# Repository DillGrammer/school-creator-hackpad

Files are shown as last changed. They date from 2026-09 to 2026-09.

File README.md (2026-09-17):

# Hackpad PCB — revision 1.0

Open **Hackpad.kicad_pro** in KiCad 10. The project includes its own symbol and footprint libraries; no care-package installation is needed. Original Desktop files were left unchanged.

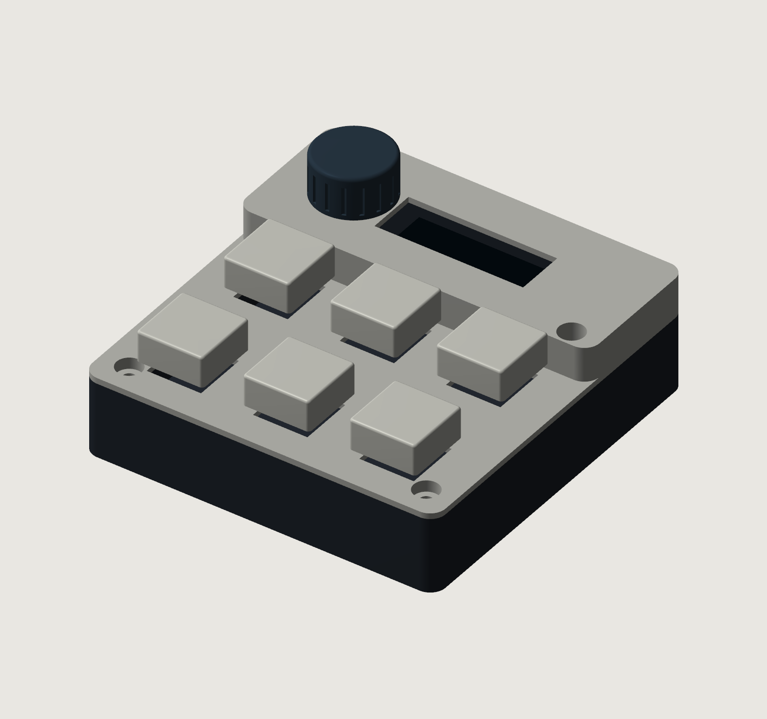
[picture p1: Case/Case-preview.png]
CAD preview of case revision 1.1


CAD visualization, not a photograph of an assembled device.

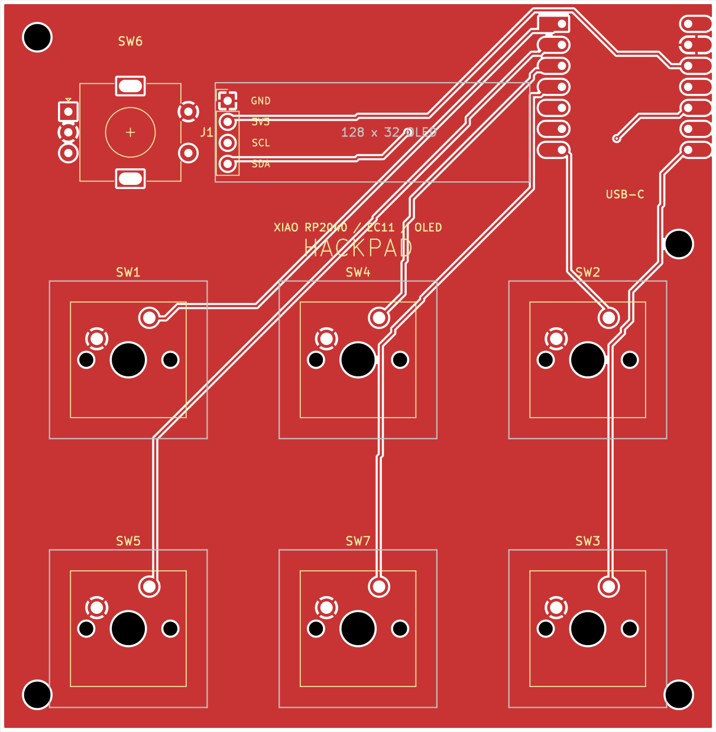
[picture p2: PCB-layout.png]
Routed two-layer PCB layout


This project was substantially generated and revised with ChatGPT/Codex assistance, following the owner's feature/layout choices and design review. See Software/Feature-status.md for unfinished integrations and Submission-status.md for funding status.

## What is finished

- 86.5 × 88.5 mm, two copper layers, 1.6 mm PCB.
- Six soldered MX switches in the established 3 × 2 layout.
- Clickable EC11 at top-left; 0.91-inch OLED immediately to its right.
- Seeed Studio XIAO RP2040 at top-right, USB-C facing the top edge.
- Routed signals, front/back ground pours, four 3.2 mm mounting holes.
- ERC, DRC and schematic parity reports included. All report zero issues.
- Gerber copper, masks, silkscreens, outline, and separate plated/non-plated drill files included.

The matching case is supplied in **Case/** as STEP and STL files, with an assembly guide and geometry checks. The native Fusion `Case/Hackpad_Case.f3d` includes editable base/cover features and a positioned knob. Case revision 1.1 corrects the CAD Y direction and knob placement; use the new case files, not earlier archives. Actual firmware and desktop-helper source are included in **Software/**; this is a development build, not a hardware-tested release. See **Software/Feature-status.md** for the exact remaining integration work.

## Pin map

View from above, USB-C at the top. Key numbers describe physical positions; existing SW references are preserved.

| Control | Reference / pad | XIAO label | RP2040 GPIO | Net |
|---|---|---|---|---|
| Top-left key | SW1 / 1 | D0 | 26 | KEY1 |
| Top-middle key | SW4 / 1 | D2 | 28 | KEY2 |
| Top-right key | SW2 / 1 | D6 | 0 | KEY3 |
| Bottom-left key | SW5 / 1 | D1 | 27 | KEY4 |
| Bottom-middle key | SW7 / 1 | D3 | 29 | KEY5 |
| Bottom-right key | SW3 / 1 | D7 | 1 | KEY6 |
| Encoder rotation A | SW6 / A | D10 | 3 | ENC_A |
| Encoder rotation B | SW6 / B | D9 | 4 | ENC_B |
| Encoder press / Enter | SW6 / S1 | D8 | 2 | ENC_CLICK |
| OLED data | J1 / 4 | D4 / SDA | 6 | OLED_SDA |
| OLED clock | J1 / 3 | D5 / SCL | 7 | OLED_SCL |
| OLED power | J1 / 2 | 3V3 | — | +3V3 |
| OLED ground | J1 / 1 | GND | — | GND |

All key pad 2 connections, encoder C, and encoder S2 connect to ground. Enable input pull-ups and software debounce for keys and encoder press. Use a quadrature decoder for rotation; configure its transitions-per-detent for the supplied encoder so one detent produces one menu step. Reverse direction in firmware if needed. Encoder press is independently wired and can mean Enter/select or another action by mode.

Six keys + three encoder inputs + two OLED signals use all 11 exposed GPIOs. Independent key wiring supports simultaneous presses without a switch matrix or diodes. Extra kit LEDs are not fitted in this design.

## Parts used from the published kit

| Quantity | Part |
|---:|---|
| 1 | Standard Seeed Studio XIAO RP2040, not RP2040 Plus |
| 6 | MX-style through-hole switches |
| 6 | 1u DSA keycaps |
| 1 | EC11 clickable rotary encoder |
| 1 | 0.91-inch 128 × 32 I²C OLED, GND–VCC–SCL–SDA |
| 1 | 4-pin 2.54 mm header supplied with/for OLED |
| 4 | M3 × 16 mm case screws, for planned enclosure |
| 4 | M3 heat-set inserts, for planned enclosure |

## Assembly assumptions

- The supplied encoder matches the Hackpad-style EC11 footprint: A/C/B terminals at 2.5 mm pitch, click terminals opposite, and two slotted metal anchors. Nominal shaft height is 20 mm. A knob is not listed in the published kit; a printable knob can be matched to the supplied shaft during case completion.
- OLED is mounted display-up and extends rightward from J1. **J1 pins run top-to-bottom: GND, 3V3, SCL, SDA.** The module envelope is assumed to be 38 × 12 mm; it is shown in the project footprint and drawing layer. Confirm the actual supplied module uses that header orientation before soldering.
- OLED is powered from 3.3 V. The common module includes I²C pull-ups; confirm that the supplied module has pull-ups to 3.3 V. Do not connect I²C pull-ups to 5 V. The MCU's weak internal pull-ups alone are not the design basis for a reliable I²C bus.
- XIAO uses the existing care-package hybrid footprint, with corrected RP2040 schematic pin names. Direct solder mounting is assumed for the planned case; tall sockets change the case fit.
- USB supplies the XIAO directly. Its 5 V breakout is deliberately unused. The circuit has no battery input.
- Switches are soldered, not hot-swap. The upper row was aligned to a common centre line; the original column spacing and lower row were preserved.
- EC11 switch anchor pads are mechanical only. They do not substitute for the C/S2 ground connections.

## Mechanical coordinates

Millimetres from PCB top-left; X right, Y down.

| Item | X | Y |
|---|---:|---:|
| Key column centres | 15.50 / 43.25 / 71.00 | — |
| Key row centres | — | 43.50 / 76.00 |
| Encoder shaft centre | 15.75 | 16.00 |
| OLED GND header pin | 27.50 | 12.19 |
| XIAO footprint centre | 75.50 | 10.50 |
| Mount H1 | 4.50 | 4.50 |
| Mount H2 | 82.00 | 29.50 |
| Mount H3 | 4.50 | 84.00 |
| Mount H4 | 82.00 | 84.00 |

The matching case uses a rounded base and removable stepped cover, four M3 screws and heat-set inserts. See **Case/Assembly-guide.md** for the assembly order, printing orientation and component fit assumptions.

## Manufacturing files

Use the Gerbers ZIP, including both drill files, for the PCB only. Board specification: two layers, FR-4, 1.6 mm thickness; design uses 0.25 mm traces, 0.20 mm minimum clearance, 0.60/0.30 mm vias, and 0.50 mm minimum copper-to-edge clearance. The Stardance design project has been created; no funding application or manufacturing order has been submitted. See Submission-status.md.

The checks validate the CAD files; this design has not been physically assembled or tested. The case has CAD checks but no physical print test; software has automated logic/display tests but still requires hardware and app integration testing.

## Sources

- [Hackpad / Stardance](https://hackpad.hackclub.com/)
- [Hack Club published kit contents](https://blueprint.hackclub.com/hackpad/parts)
- [Hackpad component guidance](https://hackpad.hackclub.com/add-components)
- [Seeed XIAO RP2040 pin map](https://wiki.seeedstudio.com/XIAO-RP2040/)

Footprints are derived from KiCad's installed libraries and the user's existing Hackpad care package. The XIAO's fabrication graphics were retained, and its courtyard added. The OLED header footprint was expanded to describe the full module envelope.

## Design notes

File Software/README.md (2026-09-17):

# Hackpad software — development build

This folder contains actual CircuitPython firmware, a Mac/Windows Python helper, and automated tests. It is **not a hardware-tested release**. Read `Feature-status.md` before relying on advanced actions.

## Install the helper

1. Install Python 3.11 or newer from python.org, including Tk support (the standard python.org installer includes it).
2. On Mac, open `Start-Mac.command`; on Windows open `Start-Windows.cmd`. First launch creates a local environment and installs dependencies from PyPI. Internet access is needed for that installation.
3. In the setup window, use **Import settings** to load your private settings file, or fill the tabs manually. Choose folder locations with **Choose…**. Missing entries disable only their associated actions.
4. Save settings. They stay in your user account's Hackpad application-data folder. Passwords and API keys are not in the firmware or public project.
5. For Quick Answer, set a vision-capable OpenAI API model and enter its key through **Set AI key privately**. The key is stored in the OS credential store. This is a separate API workflow from ChatGPT browser conversations.
6. macOS may request Accessibility/Input Monitoring for keyboard actions and Screen Recording for captures. Only enable the permissions for the Python/helper you choose to run. No permission is bypassed automatically.

If you enable the optional separate helper browser, install its Chromium runtime once with `.venv/bin/python -m playwright install chromium` on Mac, or `.venv\Scripts\python.exe -m playwright install chromium` on Windows. Log in in that separate browser when prompted. Existing browser sessions are not copied. Chat drafts are never sent automatically and video uploads are never published or scheduled.

## Install firmware

1. Download the stable CircuitPython UF2 **for Seeed Studio XIAO RP2040**, not another XIAO board: https://circuitpython.org/board/seeeduino_xiao_rp2040/
2. Enter the board's BOOTSEL mode and copy the UF2 to its boot drive. Wait for `CIRCUITPY` to appear.
3. Copy the contents of `firmware/` to the root of `CIRCUITPY`, including `lib/`, `font5x8.bin`, `engine.py`, `device.json`, `boot.py`, and `code.py`.
4. Reconnect USB. The firmware uses the exact pin map in the PCB project. Default OLED I²C address is 0x3C. In `device.json`, adjust encoder divisor (typically 2 or 4) and direction if one detent is not one menu step. Check the supplied encoder instead of assuming its pulse count.
5. Start the helper and choose Mac or Windows on the OLED. The helper scans common XIAO/CircuitPython USB vendors and confirms a protocol handshake before accepting commands. If needed select the serial port explicitly in Setup.

No UF2 has been flashed here and no physical OLED/input test has been performed. USB endpoint compatibility, memory usage and the downloaded CircuitPython release must be checked on the board. The firmware uses USB serial only; the helper is the single action dispatcher, so HID and helper commands cannot double-fire. It does not act as a standalone keyboard without the helper.

## Controls

- Boot: turn and click to choose Mac/Windows.
- Root pages: turn to Courses, Creator, Gaming (Windows), Apps, or More. Titles are brief; six labels remain visible on normal grids.
- Course and action grids: press the corresponding physical key. Small dialogs use turn-and-click.
- Back: hold bottom-right key, click encoder. The sixth key's ordinary action happens on release only if the combination did not consume it.
- CapCut: knob scrubs; click plays/pauses. Hold Volume or Trim and turn to adjust. Tap Volume enters adjustment; Trim lets you choose start/end. Hold Undo for 0.6 seconds for Redo.
- Gaming: at its root page, turn still changes categories. Click once (or press a gaming key) to enter volume control. After that, rotation controls only the foreground app's audio. Back returns to category rotation. This explicit entry avoids guessing whether a turn means category change or volume.
- Gaming keys: Fortnite / Valorant / Discord / Spotify / Next / Previous. OLED shows foreground-app icon/name, volume, and the selected headset microphone's Windows mute state. Unknown mic state displays `?`. A hardware mute switch needs device-specific verification.

## Configuration and fallbacks

School URLs and conversation URLs remain editable. The supplied Math conversation is reused; screenshots and text are prepared without pressing Send. The default reliable path presents a local draft plus an Open Conversation button and screenshot. Optional browser attachment depends on the actual page having its expected editor/file input; it refuses to overwrite a nonempty draft.

CapCut bindings are intentionally explicit in Setup. Enter comma-separated key names, such as `command,z` for an actual verified Mac Undo binding. Each action checks that CapCut is foreground before injecting keys. There are no assumed bindings for volume, trimming or presets; if the installed application does not expose a suitable shortcut, that operation needs a native accessibility adapter and currently reports missing configuration. Do not invent key combinations to make a control appear complete.

Import Recent identifies a stable recent supported file. On Mac, the native import adapter enters the path and checks the selected filename before pressing Import; this adapter still needs an end-to-end helper test. Windows currently copies the path for manual selection.

For Photos on Mac, choose Import → Photos → Open Photos, select one photo or video in Photos, then choose Import chosen on the pad. The helper exports that selected original into its retained imported-media folder, opens CapCut and requests import. macOS Automation permission for Photos is required. The Photos adapter is implemented against the installed Photos scripting dictionary but has not been integration-tested. Live Photos that export both a still and a video require choosing the desired exported file with Selected. Do not delete retained imported media while a CapCut project references it. Windows uses Selected instead.

Export opens the configured dialog, showing the configured Fitness destination; it does not yet verify/apply export settings or detect completion automatically. Set the completed output in Setup before Prepare Upload.

On Windows, an empty app path triggers discovery of exact-name Fortnite, VALORANT, Discord, Spotify or CapCut shortcuts in the user/shared Start Menus and Desktop. A configured path takes precedence. Missing shortcuts still require choosing the app in Setup; discovery has automated filesystem tests but has not been tried on the user's gaming PC.

## Tests

Run `python3 -m unittest discover -s tests -v` from this folder. Tests cover state transitions, held-key consumption, grid dimensions, framebuffer rendering, and non-overwriting copies. They do not prove hardware timing, platform permissions, application UI behavior or physical fit.

## Dependencies

OLED libraries/font come from the official Adafruit repositories; licenses are under `firmware/licenses/`. Dependency hashes are recorded in the packaged manifest. The desktop requirements are in `helper/requirements.txt`. Runtime credentials, browser profiles, screenshots and private settings must never be committed to the public repository.

### Active Word document → class folder

The course Copy key now targets the Word document being edited in the active Safari tab on Mac. It uses Word’s File → Create a Copy → Download a copy command, waits for a new complete DOCX matching that document’s title, and copies it without overwriting existing class files. The original online document stays open. Set each class folder in Setup. Safari must download automatically into Downloads, or set `word_downloads_folder` to its actual destination; Ask for each download requires manual intervention. The helper needs Mac Accessibility permission. English Word control labels were inspected in Safari; the helper’s native adapter itself still requires an end-to-end runtime test. Windows support for this action is not implemented.

### Validation update

The Mac dependency installation and import checks pass, including Tk after installing the missing Homebrew Tk component. The setup window itself has not been launched through computer control because that tool blocks Terminal. Startup now tracks the requirements file and retries dependency installation after failures or changes. Mac CapCut defaults were read from its Shortcuts window: Space, Command-Z, Command-Shift-Z, Command-I, Command-E. Advanced commands remain unconfigured. Upload preparation locally decodes the complete selected video, requires 1080×1920 at approximately 30 fps, checks that the file did not change, and stops on cancellation before attachment. It never publishes.

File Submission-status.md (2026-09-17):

# Submission status — September 17, 2026

**Not submitted. This is a development package, not a completed/validated build.** The user authorized submission after completion; that condition has not yet been met.

The [School & Creator Hackpad project](https://stardance.hackclub.com/projects/63122) now exists in the signed-in Stardance account. Its stage is Design. The factual description and substantial AI-assistance declaration were saved and confirmed by the site. No devlog, funding application, grant claim or shipment has been submitted.

The project currently shows zero devlogs and zero hours. Submit for funding is disabled. The devlog form explicitly says: "Timelapse for at least 15m before devlogging (currently 0m logged)." No unrelated project time was linked and no recording or human work hours were fabricated.

The [public source repository](https://github.com/DillGrammer/school-creator-hackpad) is now published and linked on Stardance. It includes the PCB, Gerbers, native Fusion/STEP/STL files, software source, tests and images. A CAD-render banner was attached and explicitly identified as a render in the description. The separate public staging tree excludes private settings, school links, raw conversation attachments and local error logs.

For this project the appropriate first submission is the **Hackpad design/kit stage**, not a claim that physical assembly is complete. The official mission lists kit, PCB and printing support after design; build rewards are separate. The public hardware guide asks for CAD STEP, PCB source, firmware, BOM and README, with a public repository. See [Hackpad mission](https://stardance.hackclub.com/missions/hackpad) and [hardware submission guide](https://stardance.hackclub.com/resources/shipping-hardware).

Prepared: PCB source and libraries, Gerbers, zero-issue ERC/DRC reports, STEP/STL case files, firmware/helper development source, automated tests, BOM and documentation.

Remaining:

- Native Fusion export is now produced. Case revision 1.1 fixes the knob placement and handedness. Physical fit is still untested.
- Finish and validate the advanced CapCut, Photos and upload adapters detailed in Software/Feature-status.md. Current fallback paths are documented; they are not full automation.
- Hardware input/display checks and Windows audio/headset checks require the actual board and Windows PC. Design-stage review may precede physical assembly, but evidence must describe that honestly.
- Keep the published development repository synchronized with reviewed fixes. Do not include Private settings, completed setup sheet, personal conversation URLs, screenshots of schoolwork, API keys, or browser profiles.
- The owner must supply authentic recorded work and their own devlog through Stardance's normal workflow; funding submission is currently disabled. This is distinct from physical assembly, which is not required for the design stage.
- Complete the real mission form with factual details; do not fabricate tracked hours, devlogs, eligibility or build photos. Any required personal answers must come from the user.

The published kit specification lists the matching XIAO, MX switches, EC11, 0.91-inch GND/VCC/SCL/SDA OLED, M3×16 screws and M3×5×4 inserts: [kit contents](https://blueprint.hackclub.com/hackpad/parts). Module/shaft variations and print tolerances still need fit confirmation.

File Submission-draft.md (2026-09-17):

# Proposed Stardance design-stage submission

Six-key Hackpad for school, video editing and Windows gaming, with a clickable encoder and a 128×32 OLED. The two-layer 86.5×88.5 mm PCB uses a XIAO RP2040 and direct switch wiring. The OLED sits immediately to the right of the encoder, and USB-C exits at the top.

The case uses two printed shell parts, four M3 screws and heat-set inserts, plus an optional printed knob. Revision 1.1 corrects the CAD orientation and knob placement. Editable Fusion, STEP, STL, KiCad source, Gerbers, pin map, BOM and software source are included in the development archive.

Status: design and software prototype, not a physically assembled product. The case is checked against modeled component envelopes; exact supplied parts and print fit still need confirmation. Firmware input/display logic and selected helper functions have automated tests. Several app integrations remain unfinished or unverified, as listed in Software/Feature-status.md.

AI assistance: code, PCB/CAD generation and automated checks were assisted by Codex. No human work hours, physical build evidence or eligibility claims are supplied by this draft.

This draft has not been submitted. Appropriate route after readiness review: design funding/kit request, not an assembled-build reward claim. Required personal or eligibility responses must be supplied by the project owner.

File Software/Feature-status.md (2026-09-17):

# Feature status — September 17, 2026

A function having source code is not equivalent to being validated on the user's computer or hardware.

| Area | Implemented | Remaining verification/work |
|---|---|---|
| Input/menu firmware | Actual state machine, physical pins, debounce, OLED grids, OS selection, global Back, held controls | Flash and test actual XIAO/OLED/encoder; confirm detent divisor |
| Helper setup | GUI, folder pickers, private JSON import, OS key store | Mac dependencies installed and imported successfully; GUI launch requires user action because Terminal is blocked by computer control; Windows installation untested |
| USB protocol | Handshake, bounded queues, duplicate IDs, cancellation, reconnect, OS mismatch rejection | Physical USB testing |
| Courses | Configured URL launch, drafts, screenshot capture, folder picker, rename, username entry; active Safari Word download-and-copy adapter | Word adapter source not yet run end-to-end; Mac Accessibility permission; class folders; Windows Word adapter not implemented |
| Quick Answer | On-demand capture, API request, short OLED answer, explanation log, cancellation | API model/key and real capture tests |
| ChatGPT drafts | Local draft fallback; optional browser fill/attachment without Send | Validate current ChatGPT editor/attachment behavior and login |
| CapCut basic controls | Foreground-checked configurable shortcuts; Mac play/pause, undo, redo, import and export defaults read from CapCut | Test commands on media; Windows shortcuts and advanced controls unverified |
| CapCut volume/trim/text/transition | Dispatcher and configurable bindings | Native app adapter where no shortcut exists; preset selection not implemented |
| Media import | Recent/selected file handling; Mac native picker adapter; selected-original Photos export and separate Open/Import menu | End-to-end helper test for Mac picker and Photos permissions/export; Windows uses manual path fallback |
| Export | Export shortcut and Fitness destination prompt | Set/verify 1080×1920 30 fps settings, execute export, verify completion automatically |
| Upload preparation | Optional file-input attachment; manual fallback; no publish/schedule code | Real video decoding now rejects incomplete files and non-1080×1920/30 fps exports; both real upload editors still require validation |
| Gaming | Launch targets, exact-name installed Windows shortcut discovery, Spotify-specific transport, per-app volume, foreground icon, selected headset capture-endpoint mute | Windows and actual headset tests |
| Case | Revision 1.1 STEP/STL and native Fusion F3D; corrected handedness and knob position; solid and mesh checks | Physical fit check; actual kit dimensions |
| Submission | Public DillGrammer/school-creator-hackpad repository; Stardance design project 63122 with source link, CAD render, factual description and AI declaration | Authentic recorded work/devlog and advanced integration work; funding submission remains disabled |

Do not submit this as a fully tested or physically assembled product. Do not invent hours, devlogs, photographs, build evidence or eligibility claims. Generated mockups are not photos of a real build.

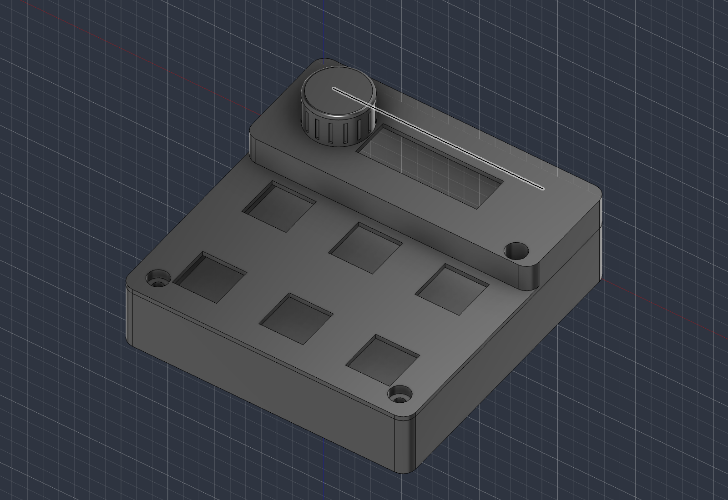
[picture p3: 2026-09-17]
Case/Fusion-preview.png

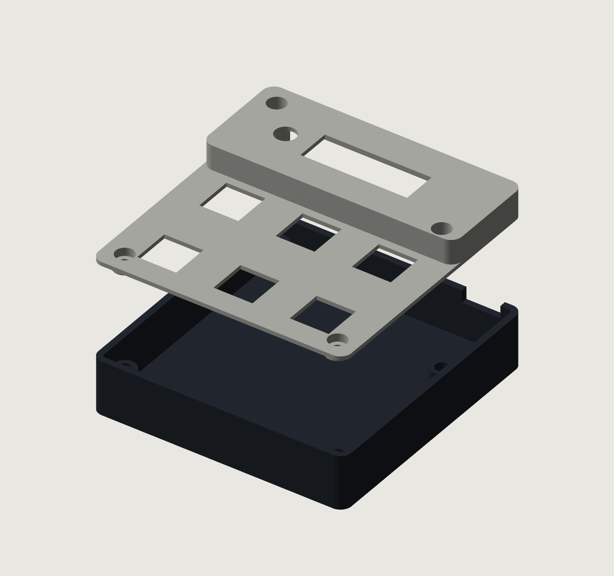
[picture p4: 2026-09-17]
Case/Case-exploded.png

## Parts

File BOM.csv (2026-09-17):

Item | Quantity | Specification | Source | Notes
Microcontroller | 1 | Seeed Studio XIAO RP2040 | Hackpad kit | Direct solder mounting; not RP2040 Plus
Switch | 6 | MX through-hole | Hackpad kit | Soldered; no hot-swap sockets
Keycap | 6 | 1u DSA | Hackpad kit | Blank white
Rotary encoder | 1 | EC11 with push switch | Hackpad kit | Confirm shaft geometry against case
OLED | 1 | 0.91 inch 128x32 I2C | Hackpad kit | Pin order GND VCC SCL SDA
OLED header | 1 | 1x4 2.54mm | OLED hardware | Nominal module underside 8.5mm above PCB
Screw | 4 | M3x16mm | Hackpad kit | Head diameter <=5.7mm and height <=3mm
Heat-set insert | 4 | M3 OD5mm length4mm | Hackpad kit | Case pilot diameter 4.6mm
PCB | 1 | 86.5x88.5mm 2-layer FR4 1.6mm | PCB fabrication | Gerbers included
Base print | 1 | Base.stl | 3D printing | No damping
Cover print | 1 | Cover.stl | 3D printing | Print orientation supplied
Knob print | 1 | Knob.stl | 3D printing | Optional; nominal 6mm D shaft
USB cable | 1 | USB-C data cable | User supplied | Data-capable cable required

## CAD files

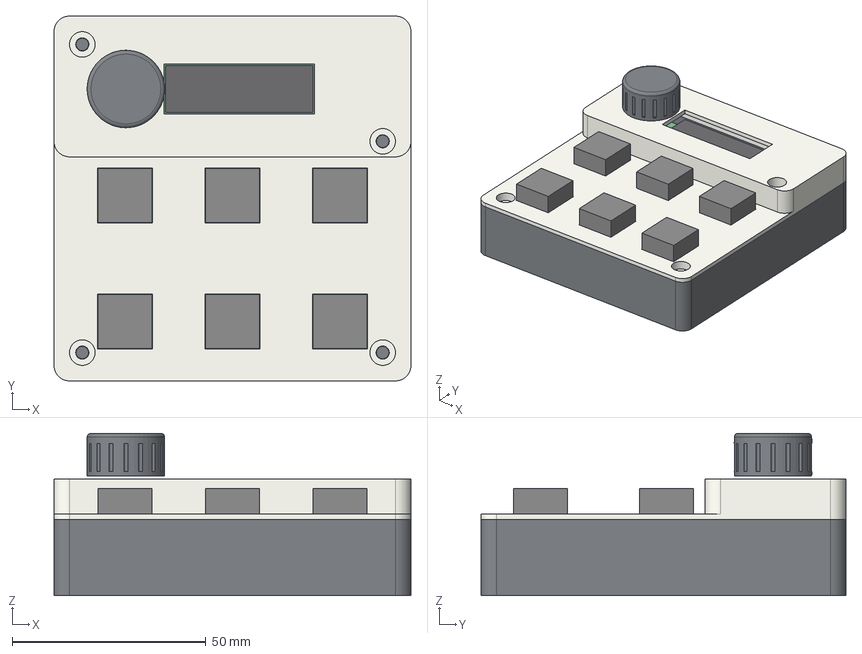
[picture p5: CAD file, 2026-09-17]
Case/Hackpad_Assembly.step
92.1 x 94.1 x 41.9 mm
Base
Cover
Knob_with_0p8mm_click_clearance
REFERENCE_PCB_envelope
REFERENCE_OLED_module
REFERENCE_XIAO_envelope
REFERENCE_switch_1
REFERENCE_switch_2
REFERENCE_switch_3
REFERENCE_switch_4
REFERENCE_switch_5
REFERENCE_switch_6

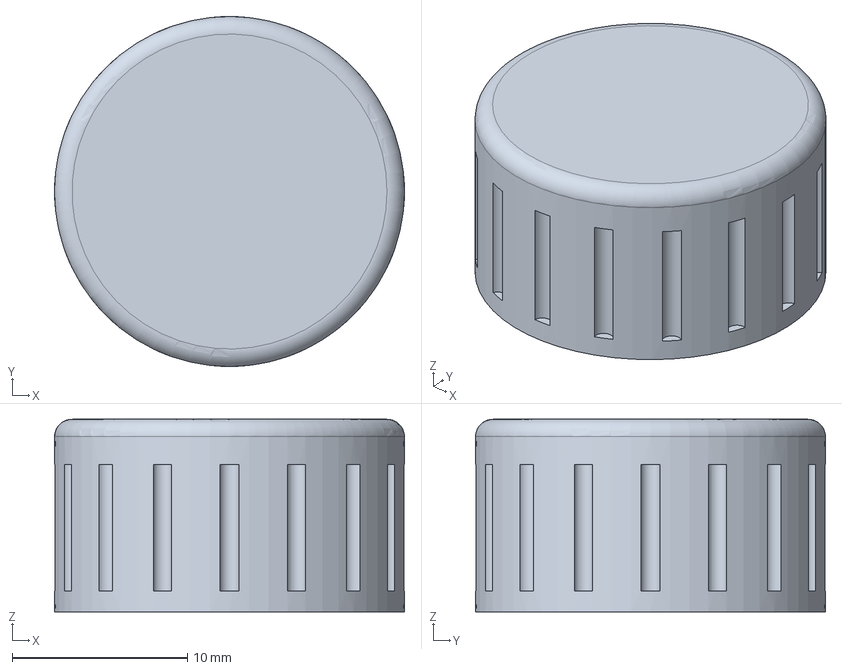
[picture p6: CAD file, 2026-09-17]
Case/Knob.step
20.0 x 20.0 x 11.0 mm

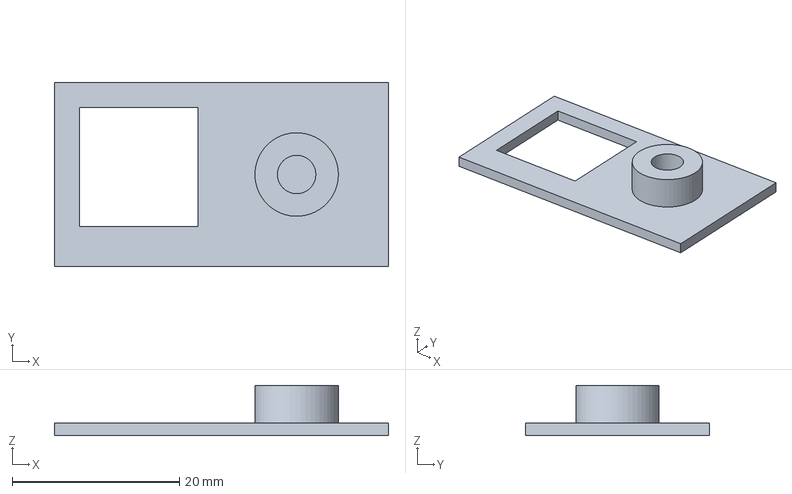
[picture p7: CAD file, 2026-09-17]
Case/Fit_coupon.step
40.0 x 22.0 x 6.00 mm

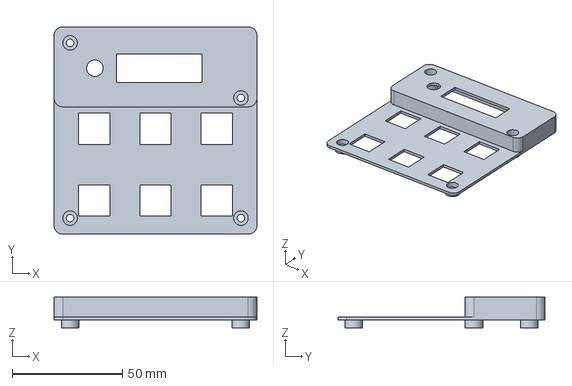
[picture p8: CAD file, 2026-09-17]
Case/Cover.step
92.1 x 94.1 x 14.0 mm

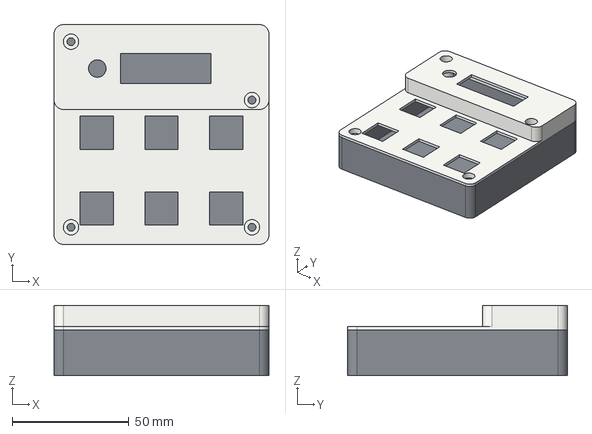
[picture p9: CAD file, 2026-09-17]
Case/Hackpad_Case.step
92.1 x 94.1 x 30.1 mm
Base
Cover

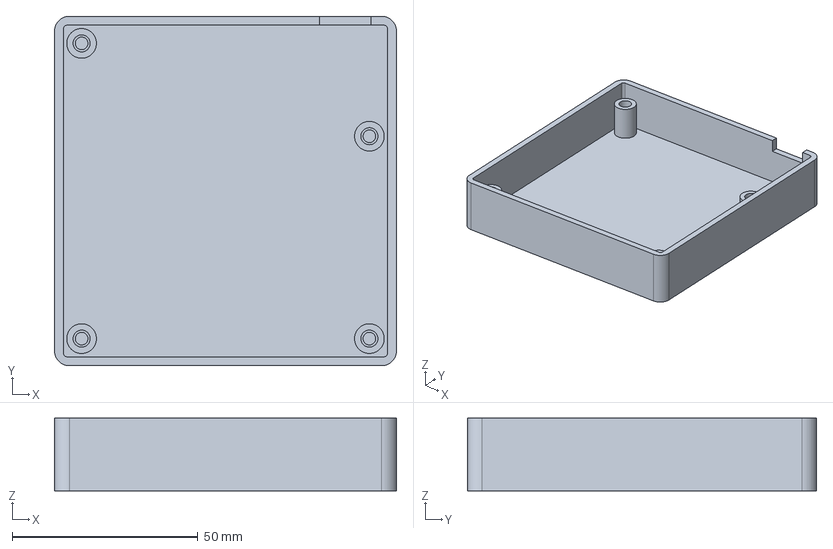
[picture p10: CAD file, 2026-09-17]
Case/Base.step
92.1 x 94.1 x 19.6 mm

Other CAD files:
Case/Base.stl
Case/Cover.stl
Case/Fit_coupon.stl
Case/Hackpad_Case.f3d
Case/Knob.stl

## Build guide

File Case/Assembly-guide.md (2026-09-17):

# Hackpad case

A simple rounded base and one removable cover, with six MX openings, a clickable encoder, an OLED recess and a USB-C opening. No foam, gaskets or damping layers are used.

## Files

- **Base.stl** and **Cover.stl**: the two main printed parts, already oriented for printing.
- **Knob.stl**: optional printed knob for a nominal 6 mm D-shaped EC11 shaft.
- **Hackpad_Case.step**: assembled solid model that can be opened in Fusion. Separate STEP files are also included.
- **Fit_coupon.stl**: optional small test of the MX opening and heat-set insert fit. It is a test piece, not part of the final case.

**Revision 1.1:** `Hackpad_Case.f3d` is the native Fusion model with editable base/cover features. The knob is centered over the encoder with its bottom at 30.9 mm, 0.8 mm above the hood. The CAD Y axis is the negative of KiCad top-view Y, so the encoder is top-left and OLED to its right. Replace earlier case files and archives; those had an incorrect handedness and native knob placement.

## Hardware

Use four M3 × 16 mm screws and four M3 heat-set inserts (assumed 5 mm outside diameter × 4 mm length). The screw recesses allow heads up to 5.7 mm diameter and 3.0 mm high. The insert pilot holes are 4.6 mm diameter and 4.2 mm deep. Install the inserts flush or slightly below the top of each base post.

The case matches the supplied Hackpad PCB revision 1.0: 86.5 × 88.5 mm, 1.6 mm thick, with mounting holes at (4.5,4.5), (82,29.5), (4.5,84), (82,84) mm. Case size is **92.1 × 94.1 mm**, 21.1 mm tall at the key plate and 30.1 mm at the control hood, excluding keys and knob.

## Assembly order

1. Remove print supports and test the switch and insert fit. Install the four heat-set inserts in the base **before fitting the PCB**.
2. Solder the XIAO directly to the PCB; fit the EC11 and OLED. The case assumes an OLED underside 8.5 mm above the main PCB, and a module up to 38 × 12 mm.
3. Snap the six MX switches into the cover from above. **Do this before soldering the switches to the PCB**; an assembled switch's upper flange cannot pass through the plate opening.
4. Bring the PCB up underneath the cover, align the six sets of switch pins, encoder shaft and OLED opening, then solder the switch pins from below.
5. Place that assembly into the base. Install the four M3 × 16 mm screws through the cover and PCB into the base inserts; tighten gently. The lower screw heads sit flush with the key plate. The upper two are reached through the recessed screw wells.
6. Fit the keycaps. If using the printed knob, align its D-shaped socket and leave **at least 0.8 mm between knob and hood** so the encoder can still be pressed. Do not force the knob fully down against the hood.

The cover comes off with four screws for later access. There are no loose internal spacers.

## Printing

A practical starting point is PLA, a 0.4 mm nozzle, 0.2 mm layers, four walls and 25–35% infill. The switch plate is 1.5 mm thick; switch openings are 14.2 mm square.

- Base.stl is bottom-down. Supports are generally unnecessary except if the printer needs help at the USB cutout.
- Cover.stl is already upside-down with the control roof toward the bed. **Enable supports from the build plate under the elevated key-plate area.** Keep support material out of the small holes when the slicer allows it. Remove supports before assembly.
- Knob.stl is socket-down; its internal roof is a short bridge.

The two colours in the preview are only a suggestion: print the base dark and cover light, or use one colour.

## Checks and fit assumptions

Each printable item is one valid CAD solid. Exported meshes have zero boundary/non-manifold edges. The modeled PCB, switches, OLED, encoder, screws and inserts have no volumetric collisions with the case. Reports are included.

Physical printing and assembly have not been tested. Before printing the full case, confirm the kit's insert dimensions, encoder shaft shape/height, OLED header height and screw head dimensions. The XIAO must be directly soldered; tall header sockets would need a case adjustment. The printed knob is optional because EC11 shaft variants differ. The preview uses illustrative keycaps and display glass.

## Additional reproducible files

`Hackpad_Assembly.step` contains the actual base, cover and optional knob with 0.8 mm click clearance, plus explicitly named REFERENCE component envelopes. The reference blocks are not manufacturer component models. Use the PCB files and component specifications for exact pin geometry.

`FusionBuild/FusionBuild.py` is the corrected native Fusion builder. Its base and cover dimensions match the checked STEP parts. In a new empty **Hybrid design**, open Scripts and Add-Ins and select this script folder, then run it. It creates editable base/cover features and imports the optional knob solid, exporting `Hackpad_Case.f3d` and a geometry report into this Case folder. The corrected script has executed successfully. Native solid volumes match the separate STEP geometry; its export includes a checked knob position. Do not use the older script in the working directory.

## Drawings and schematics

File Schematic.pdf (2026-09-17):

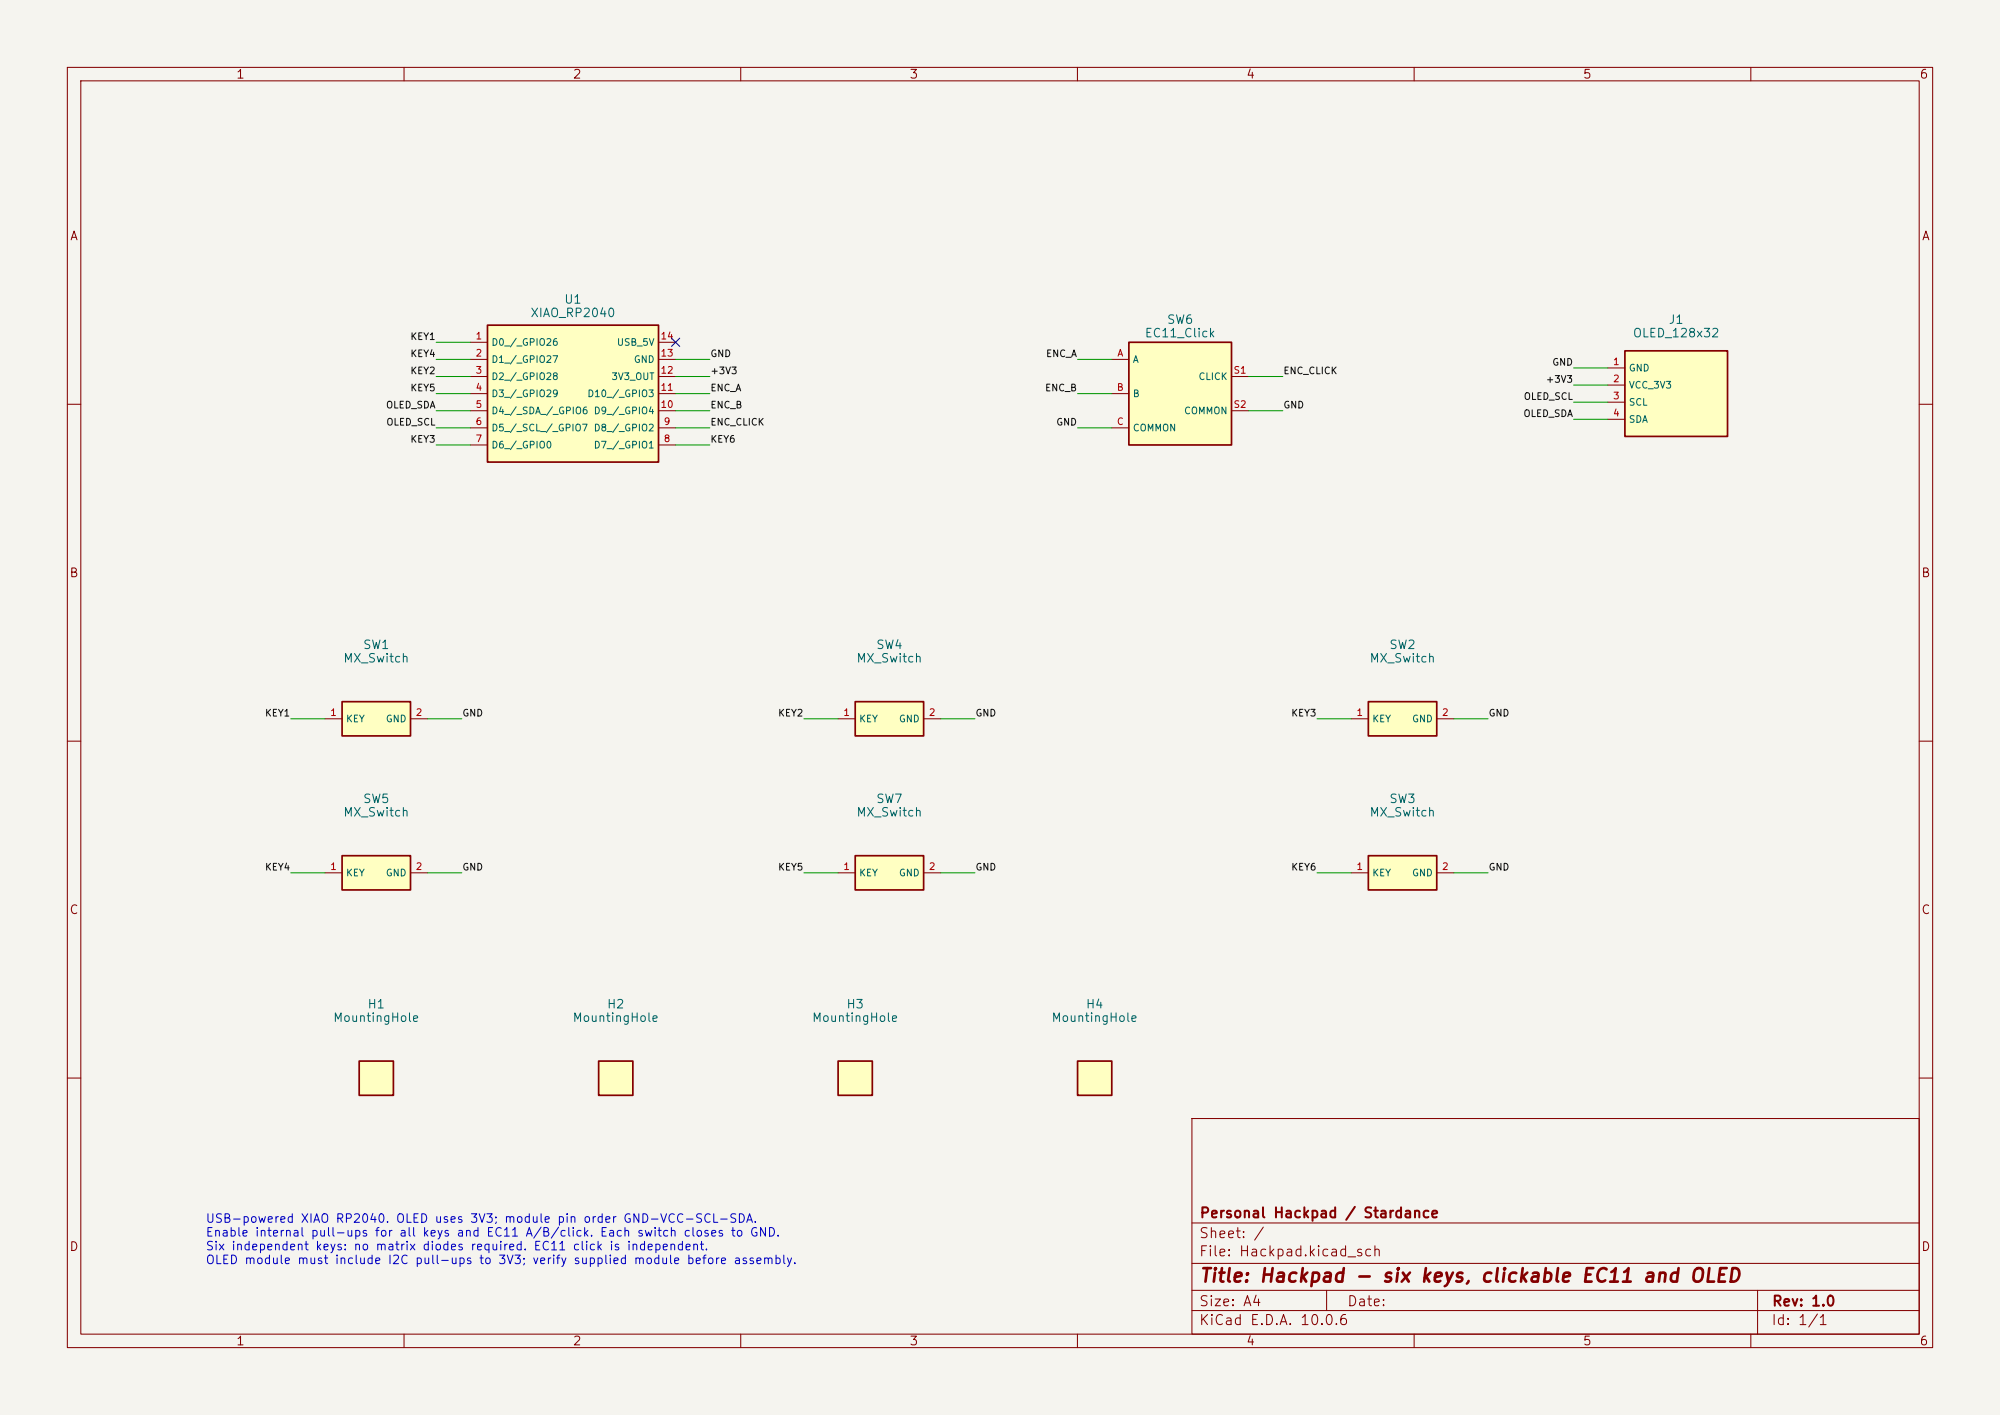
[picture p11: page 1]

Personal Hackpad / Stardance
Sheet: /
File: Hackpad.kicad_sch
Title: Hackpad - six keys, clickable EC11 and OLED

Size: A4 | Rev: 1.0
KiCad E.D.A. 10.0.6 | Id: 1/1

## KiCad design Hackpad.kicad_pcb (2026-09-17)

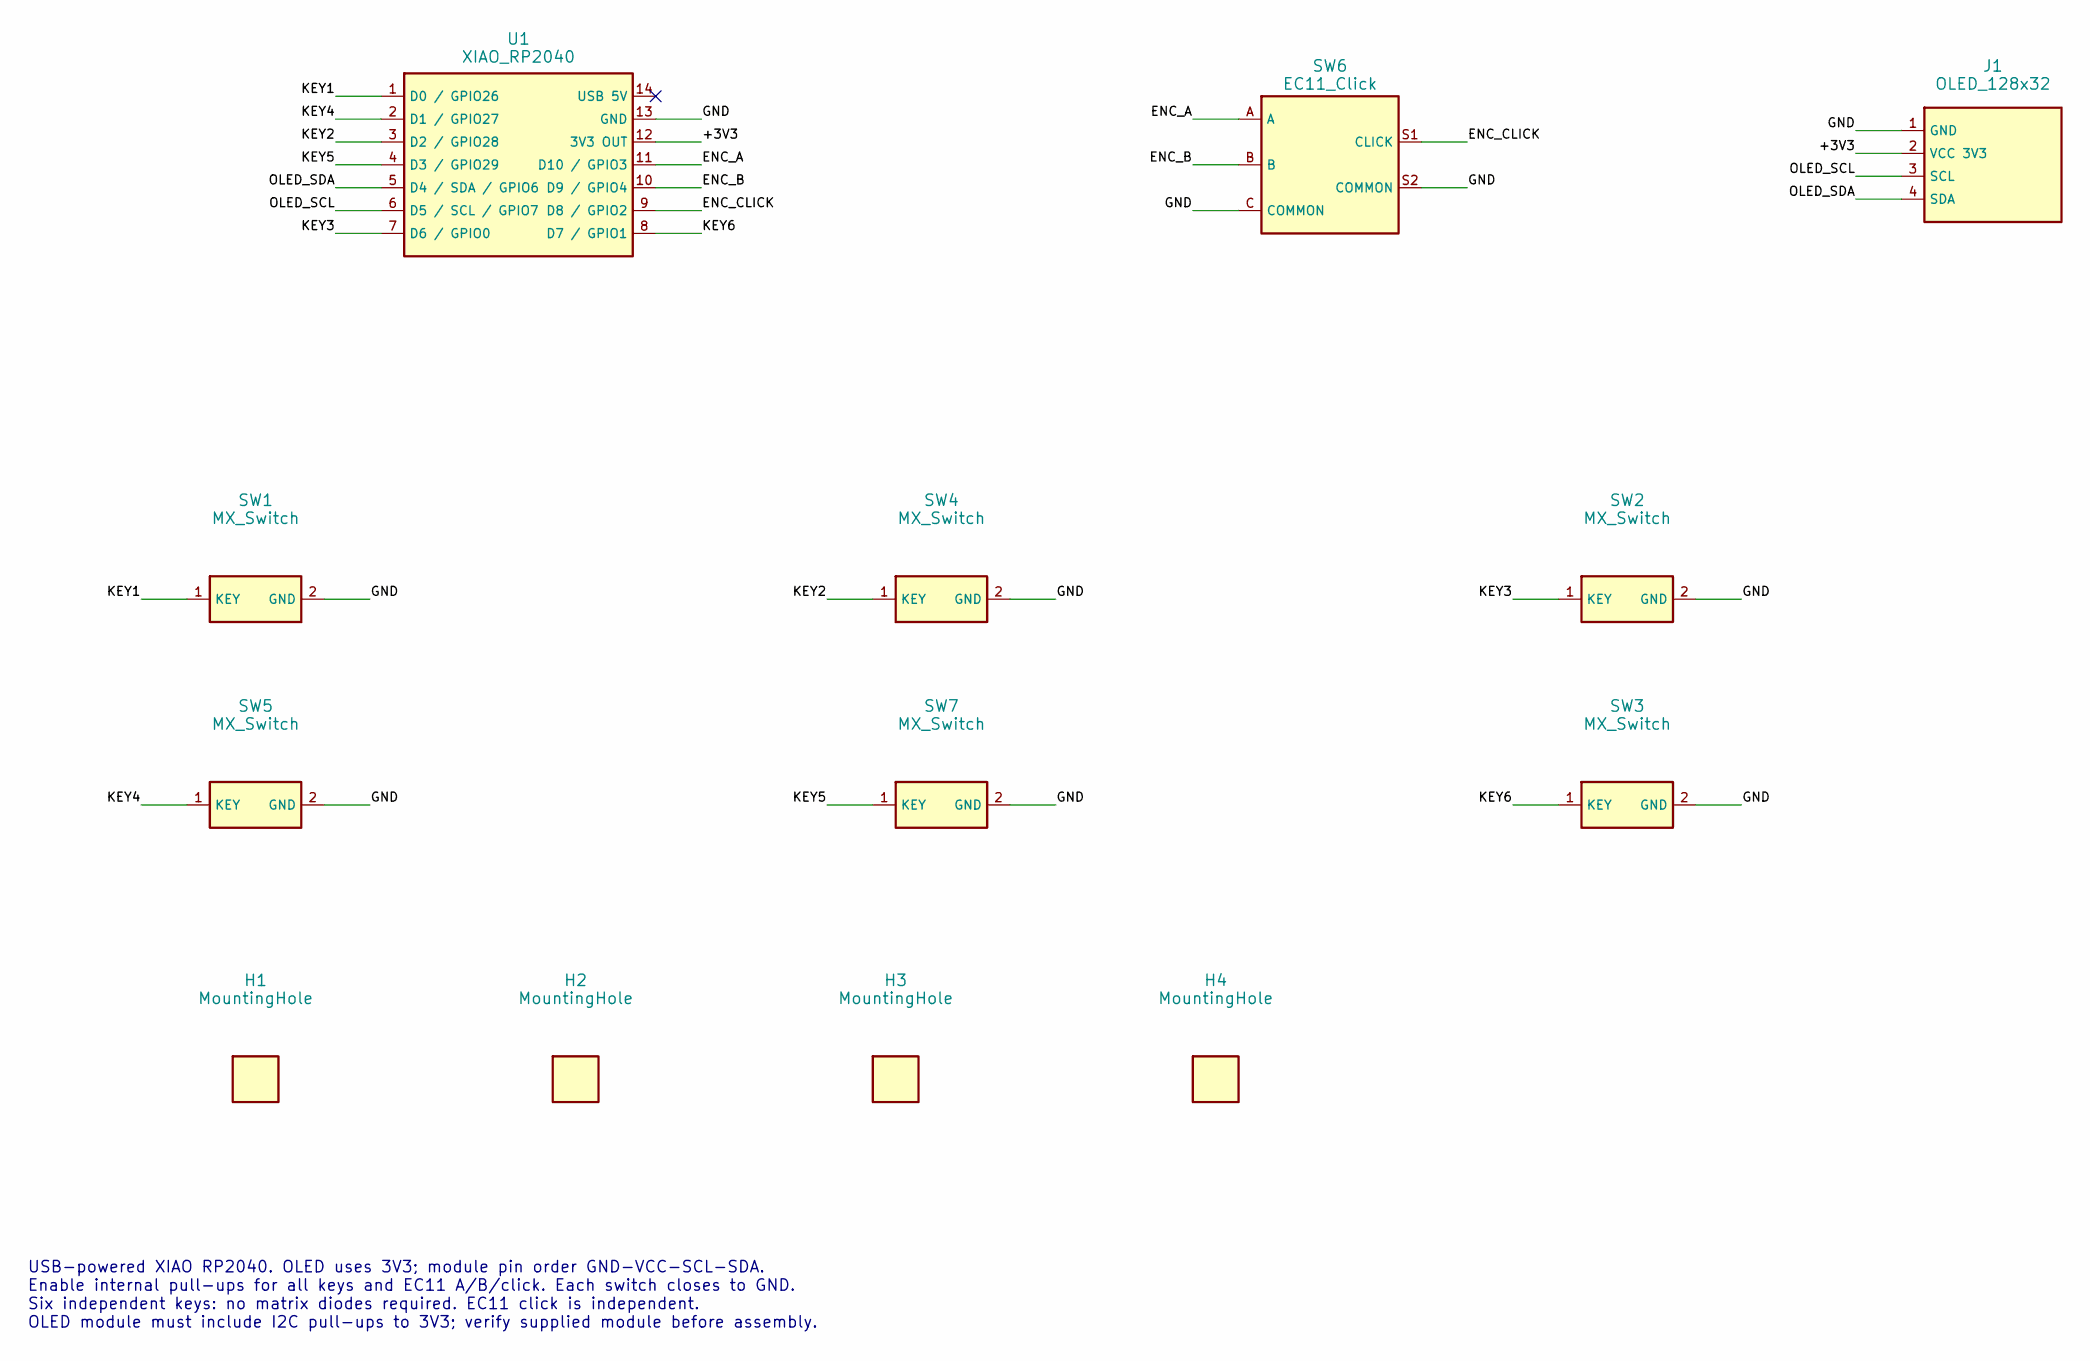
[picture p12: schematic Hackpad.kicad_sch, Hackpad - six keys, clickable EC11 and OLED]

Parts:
H1, H2, H3, H4: MountingHole; MountingHole_3.2mm_M3
J1: OLED_128x32; OLED_091_GND_VCC_SCL_SDA
SW1, SW2, SW3, SW4, SW5, SW7: MX_Switch; SW_Cherry_MX_1.00u_PCB
SW6: EC11_Click; RotaryEncoder_Alps_EC11E-Switch_Vertical_H20mm
U1: XIAO_RP2040; XIAO-Generic-Hybrid-14P-2.54-21X17.8MM

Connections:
/+3V3: J1.2 (VCC 3V3), U1.12 (3V3 OUT)
/ENC_A: SW6.A, U1.11 (D10 / GPIO3)
/ENC_B: SW6.B, U1.10 (D9 / GPIO4)
/ENC_CLICK: SW6.S1 (CLICK), U1.9 (D8 / GPIO2)
/GND: J1.1 (GND), SW1.2 (GND), SW2.2 (GND), SW3.2 (GND), SW4.2 (GND), SW5.2 (GND), SW6.C (COMMON), SW6.S2 (COMMON), SW7.2 (GND), U1.13 (GND)
/KEY1: SW1.1 (KEY), U1.1 (D0 / GPIO26)
/KEY2: SW4.1 (KEY), U1.3 (D2 / GPIO28)
/KEY3: SW2.1 (KEY), U1.7 (D6 / GPIO0)
/KEY4: SW5.1 (KEY), U1.2 (D1 / GPIO27)
/KEY5: SW7.1 (KEY), U1.4 (D3 / GPIO29)
/KEY6: SW3.1 (KEY), U1.8 (D7 / GPIO1)
/OLED_SCL: J1.3 (SCL), U1.6 (D5 / SCL / GPIO7)
/OLED_SDA: J1.4 (SDA), U1.5 (D4 / SDA / GPIO6)

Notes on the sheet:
USB-powered XIAO RP2040. OLED uses 3V3; module pin order GND-VCC-SCL-SDA. Enable internal pull-ups for all keys and EC11 A/B/click. Each switch closes to GND. Six independent keys: no matrix diodes required. EC11 click is independent. OLED module must include I2C pull-ups to 3V3; verify supplied mo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

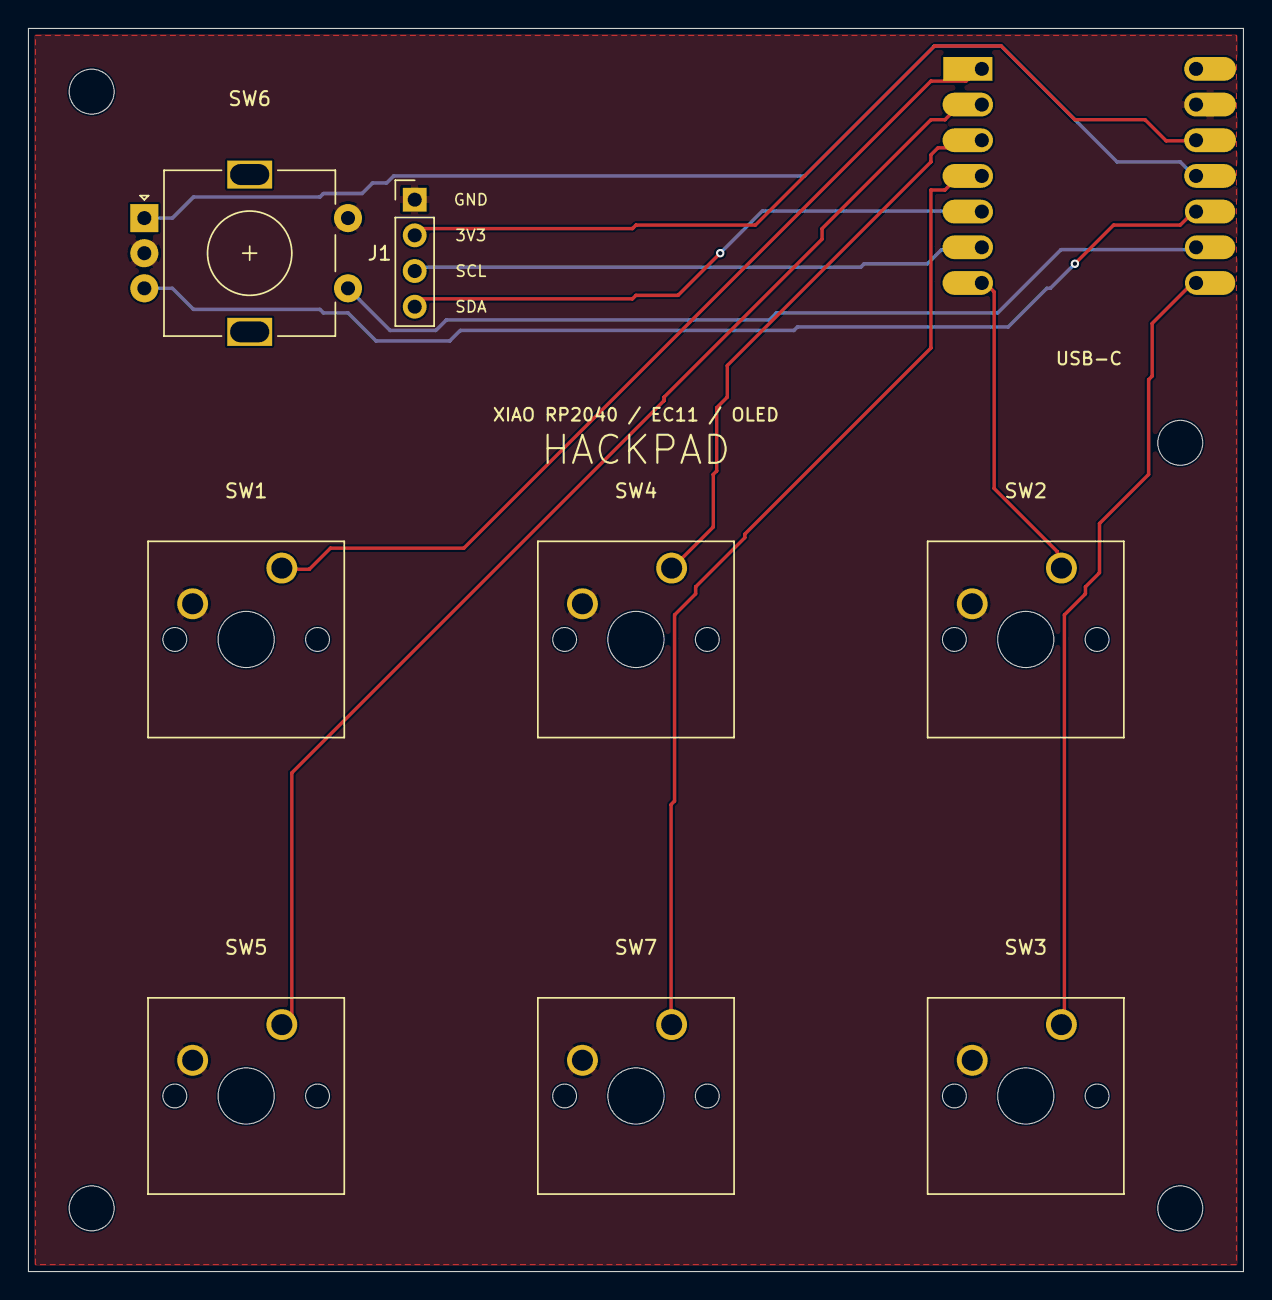
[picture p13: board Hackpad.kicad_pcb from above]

Board: 2 copper layers, 86.5 x 88.5 mm, 13 parts (0 on the bottom side), 13 nets.

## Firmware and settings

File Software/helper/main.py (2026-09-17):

"""Desktop setup UI and serial helper. Run with Python 3.11+."""
import sys,pathlib,json,threading,queue,time,webbrowser,traceback
import tkinter as tk
from tkinter import ttk,filedialog,messagebox,simpledialog
from config import load,save,location
from actions import Actions
from platform_io import NotReady

class UI:
 def __init__(self):
  self.root=tk.Tk();self.root.title('Hackpad setup');self.root.geometry('800x640')
  self.config=load();self.questions=queue.Queue();self.entries={};self.log=tk.StringVar(value='Helper starting…')
  book=ttk.Notebook(self.root);book.pack(fill='both',expand=True)
  for group in ['urls','folders','apps','general','capcut_shortcuts']:
   outer=ttk.Frame(book);book.add(outer,text=group.replace('_',' ').title())
   canvas=tk.Canvas(outer);scroll=ttk.Scrollbar(outer,orient='vertical',command=canvas.yview);body=ttk.Frame(canvas)
   body.bind('<Configure>',lambda e,c=canvas:c.configure(scrollregion=c.bbox('all')))
   canvas.create_window((0,0),window=body,anchor='nw');canvas.configure(yscrollcommand=scroll.set);canvas.pack(side='left',fill='both',expand=True);scroll.pack(side='right',fill='y')
   values=self.config.get(group,{}) if group!='general' else {k:self.config[k] for k in ['school_username','ssh_alias','ssh_host','ssh_user','serial_port','headset_microphone','ai_model','capcut_process','latest_export','word_downloads_folder']}
   if group=='capcut_shortcuts':values={k:self.config['capcut_shortcuts'].get(k,[]) for k in ['play_pause','undo','redo','import','export','text','transition','scrub_left','scrub_right','volume_left','volume_right','trim_start_left','trim_start_right','trim_end_left','trim_end_right']}
   for row,(key,value) in enumerate(values.items()):
    ttk.Label(body,text=key.replace('_',' ')).grid(row=row,column=0,sticky='w',padx=8,pady=5)
    var=tk.StringVar(value=','.join(value) if isinstance(value,list) else value);self.entries[(group,key)]=var
    ttk.Entry(body,textvariable=var,width=58).grid(row=row,column=1,padx=4)
    if group in ('folders','apps') or key in ('latest_export','word_downloads_folder'):
     ttk.Button(body,text='Choose…',command=lambda v=var,g=('folders' if key=='word_downloads_folder' else group):self.browse(v,g)).grid(row=row,column=2)
  bar=ttk.Frame(self.root);bar.pack(fill='x');ttk.Button(bar,text='Import settings',command=self.import_settings).pack(side='left');ttk.Button(bar,text='Save settings',command=self.store).pack(side='left');ttk.Button(bar,text='Set AI key privately',command=self.key).pack(side='left')
  self.browser_enabled=tk.BooleanVar(value=self.config.get('browser_attach_enabled',False))
  ttk.Checkbutton(self.root,text='Use separate helper browser for attachments (sign-in required)',variable=self.browser_enabled).pack(anchor='w')
  ttk.Label(self.root,textvariable=self.log,wraplength=760).pack(fill='x',padx=8,pady=8)
  self.root.after(100,self.poll)
 def import_settings(self):
  path=filedialog.askopenfilename(title='Import your private settings.json',filetypes=[('JSON','*.json')])
  if not path:return
  try:
   d=load(path)
   for (group,k),v in self.entries.items():
    value=d.get(k,'') if group=='general' else d.get(group,{}).get(k,'')
    v.set(','.join(value) if isinstance(value,list) else value)
   self.browser_enabled.set(bool(d.get('browser_attach_enabled',False)))
   save(d);self.config=d;self.log.set('Imported private settings. Folder paths can be chosen with Choose…')
  except Exception as e:messagebox.showerror('Import failed',str(e))
 def browse(self,var,group):
  p=filedialog.askdirectory() if group=='folders' else filedialog.askopenfilename()
  if p:var.set(p)
 def store(self):
  d=load()
  for (group,k),v in self.entries.items():
   if group=='general':d[k]=v.get()
   elif group=='capcut_shortcuts':d[group][k]=[x.strip() for x in v.get().split(',') if x.strip()]
   else:d[group][k]=v.get()
  d['browser_attach_enabled']=self.browser_enabled.get();save(d);self.config=d;self.log.set('Saved. Leave unknown settings blank; those actions will show Setup Needed.')
 def key(self):
  value=simpledialog.askstring('API key','OpenAI API key (saved in your OS credential store):',show='*')
  if value:
   import keyring
   keyring.set_password(self.config['ai_key_service'],'api_key',value)
 def ask(self,kind,value):
  reply=queue.Queue();self.questions.put((kind,value,reply));return reply.get()
 def draft(self,d):
  win=tk.Toplevel(self.root);win.title('Prepared ChatGPT draft — send it yourself')
  field=tk.Text(win,width=85,height=12);field.pack();field.insert('1.0',d['prompt'])
  def copy():self.root.clipboard_clear();self.root.clipboard_append(field.get('1.0','end-1c'))
  ttk.Button(win,text='Open same conversation',command=lambda:webbrowser.open(d['url'])).pack()
  ttk.Button(win,text='Copy draft',command=copy).pack()
  if d['image']:
   from platform_io import reveal
   ttk.Button(win,text='Show screenshot to attach',command=lambda:reveal(d['image'])).pack()
  ttk.Label(win,text='Attach the screenshot, paste the draft, then press Send in ChatGPT.').pack()
 def poll(self):
  try:
   while True:
    kind,v,q=self.questions.get_nowait();r=None
    if kind=='file':r=filedialog.askopenfilename(title=v)
    elif kind=='text':r=simpledialog.askstring('Hackpad',v)
    elif kind=='message':messagebox.showinfo('Hackpad',v)
    elif kind=='draft':self.draft(v)
    elif kind=='setup':self.root.deiconify();self.root.lift()
    elif kind=='log':self.log.set(v)
    q.put(r)
  except queue.Empty:pass
  self.root.after(100,self.poll)
 def report(self,text):self.questions.put(('log',text,queue.Queue()))

class Bridge:
 def __init__(self,ui):
  self.ui=ui;self.actions=Actions(ui.config,ui.ask);self.jobs=queue.Queue(maxsize=24);self.results=queue.Queue();self.epoch=0;self.generation=0;self.busy=False;self.lock=threading.Lock()
  threading.Thread(target=self.worker,daemon=True).start()
 def worker(self):
  while True:
   epoch,m=self.jobs.get()
   with self.lock:
    if epoch!=self.epoch:continue
    self.actions.cancelled.clear();self.actions.config=self.ui.config;self.busy=True
   try:
    if m.get('focus_pid'):
     from platform_io import foreground
     if foreground()[0]!=m['focus_pid']:raise NotReady('Focus changed; turn again')
    result=self.actions.dispatch(m)
   except NotReady as e:result=str(e)
   except Exception as e:result='Action error; see helper';self.ui.report(type(e).__name__+': '+str(e))
   finally:
    with self.lock:self.busy=False
   with self.lock:
    if epoch==self.epoch:self.results.put({'type':'result','version':1,'id':m['id'],'generation':m['generation'],'text':result})
 def cancel(self):
  with self.lock:self.epoch+=1;self.actions.cancelled.set()
 def ports(self):
  from serial.tools import list_ports
  chosen=self.ui.config.get('serial_port')
  return [chosen] if chosen else [p.device for p in list_ports.comports() if p.vid in (0x2886,0x239A,0x2E8A)]
 def run(self):
  import serial
  while True:
   for port in self.ports():
    try:
     with serial.Serial(port,115200,timeout=.1,write_timeout=.5) as s:
      self.session(s)
    except Exception as e:
     self.cancel();self.ui.report('Waiting for Hackpad: '+str(e))
   time.sleep(1)
 def session(self,s):
  rx=b'';seen=set();last_hello=time.monotonic();last_status=0;verified=False
  while True:
   data=s.read(512)
   if data:rx+=data
   if len(rx)>8192:raise ValueError('Oversized serial message')
   while b'\n' in rx:
    line,rx=rx.split(b'\n',1)
    try:m=json.loads(line)
    except ValueError:continue
    if not isinstance(m,dict) or m.get('version')!=1:continue
    if m.get('type')=='hello' and m.get('device')=='hackpad':
     verified=True;last_hello=time.monotonic();self.generation=m.get('generation',0)
     s.write(b'{"type":"ack","version":1}\n')
     self.ui.report('Connected on '+s.port)
    if m.get('type')=='action' and verified:
     if not isinstance(m.get('id'),int) or m['id'] in seen:continue
     if not isinstance(m.get('action'),str) or not isinstance(m.get('generation'),int):continue
     seen.add(m['id'])
     if len(seen)>2048:seen=set(sorted(seen)[-1024:])
     if m['action']=='cancel':self.cancel();continue
     actual='windows' if sys.platform=='win32' else 'mac'
     if m.get('os')!=actual:
      s.write((json.dumps({'type':'result','version':1,'id':m['id'],'generation':m['generation'],'text':'Wrong OS: '+actual})+'\n').encode());continue
     if m['action']=='gaming.volume':
      from platform_io import foreground
      m['focus_pid']=foreground()[0]
     if (self.busy or not self.jobs.empty()) and m['action'] not in ('gaming.volume',):
      s.write((json.dumps({'type':'result','version':1,'id':m['id'],'generation':m['generation'],'text':'Busy - finish/cancel'})+'\n').encode());continue
     try:self.jobs.put_nowait((self.epoch,m))
     except queue.Full:
      s.write((json.dumps({'type':'result','version':1,'id':m['id'],'generation':m['generation'],'text':'Busy - retry'})+'\n').encode())
   while not self.results.empty():s.write((json.dumps(self.results.get())+'\n').encode())
   now=time.monotonic()
   if verified and now-last_status>1:
    try:
     from windows_audio import snapshot
     status=snapshot(self.ui.config) if sys.platform=='win32' else {'app':'Mac','volume':None,'mic':None}
    except Exception:status={'app':'Unavailable','volume':None,'mic':None}
    status.update(type='status',version=1);s.write((json.dumps(status)+'\n').encode());last_status=now
   if now-last_hello>4:self.cancel();raise TimeoutError('Device disconnected')

if __name__=='__main__':
 ui=UI();bridge=Bridge(ui);threading.Thread(target=bridge.run,daemon=True).start();ui.root.mainloop()

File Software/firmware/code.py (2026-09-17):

"""Copy this directory to CIRCUITPY with the libraries listed in README."""
import time,json,board,busio,digitalio,rotaryio,usb_cdc,microcontroller
import adafruit_ssd1306
from engine import Engine
try:
 with open('/device.json') as f:cfg=json.load(f)
except OSError:cfg={}
i2c=busio.I2C(board.D5,board.D4)
oled=adafruit_ssd1306.SSD1306_I2C(128,32,i2c,addr=cfg.get('oled_address',60))
pins=[]
for pin in [board.D0,board.D2,board.D6,board.D1,board.D3,board.D7,board.D8]:
 p=digitalio.DigitalInOut(pin);p.switch_to_input(pull=digitalio.Pull.UP);pins.append(p)
enc=rotaryio.IncrementalEncoder(board.D10,board.D9,divisor=cfg.get('encoder_divisor',4))
serial=usb_cdc.data;serial.timeout=0;serial.write_timeout=0
queue=[];rx=bytearray();seq=0;last_ping=0;last_host=-100;notice='';notice_until=0
status={};last_frame=None;last_page=None;title_until=0;title=''
def emit(msg):
 global seq,notice,notice_until
 seq+=1;msg.update(type='action',id=seq,version=1)
 if msg['action']=='os_changed':microcontroller.nvm[0]=1 if msg['os']=='windows' else 0
 if msg['action']=='cancel':
  notice_until=0
 if time.monotonic()-last_host>4:
  notice='Helper offline';notice_until=time.monotonic()+1.5;return
 if len(queue)<24:queue.append((json.dumps(msg)+'\n').encode())
 else:notice='Busy - retry';notice_until=time.monotonic()+1.5
engine=Engine(emit,'windows' if microcontroller.nvm[0]==1 else 'mac')
raw=[False]*7;stable=raw[:];changed=[0]*7;pos=enc.position;last_draw=0;tx=b''
def text(s,x,y):oled.text(''.join(c if 32<=ord(c)<127 else '?' for c in str(s))[:21],x,y,1)
def grid(labels):
 oled.vline(42,0,32,1);oled.vline(85,0,32,1);oled.hline(0,15,128,1)
 for i,l in enumerate(labels):
  # SSD1306 framebuffer font is 5px ink/6px advance with supplied font5x8.bin.
  x=[0,43,86][i%3];width=[42,42,42][i%3]
  text(l,x+max(0,(width-len(l)*6)//2),4+(i//3)*16)
def draw(now):
 oled.fill(0)
 if now<notice_until:
  text(notice[:21],0,0);text(notice[21:42],0,10);text(notice[42:63],0,20)
 elif now<title_until:text(title,0,12)
 elif engine.page=='boot':text('Choose computer',0,0);text(('> MAC' if engine.index==0 else '  MAC'),0,12);text(('> WINDOWS' if engine.index==1 else '  WINDOWS'),0,24)
 elif engine.page=='selector':
  text(engine.title.upper(),0,0);text('>'+engine.options[engine.index][0],0,12);text(str(engine.index+1)+'/'+str(len(engine.options)),0,24)
 elif engine.page=='adjust':text(engine.title.upper(),0,0);text('Turn to adjust',0,12);text('Click to finish',0,24)
 elif engine.page=='gaming' or (engine.page=='root' and engine.roots()[engine.root]=='Gaming'):
  app=status.get('app','Offline')[:13];text(app,17,1)
  # Simplified monochrome app glyphs; no color assets required.
  icon=status.get('icon','app')
  if icon=='spotify':
   oled.rect(0,1,14,13,1)
   for y,w in [(4,10),(7,8),(10,6)]:oled.hline(2,y,w,1)
  elif icon=='valorant':oled.line(1,2,7,13,1);oled.line(7,13,13,2,1)
  elif icon=='fortnite':text('F',4,3)
  elif icon=='discord':oled.rect(0,3,14,9,1);oled.pixel(4,7,1);oled.pixel(10,7,1)
  else:oled.rect(1,2,12,11,1)
  mute=status.get('mic')
  oled.rect(116,1,5,8,1);oled.line(113,7,113,11,1);oled.hline(113,11,11,1);oled.vline(118,11,4,1)
  if mute is True:oled.line(111,1,125,15,1)
  elif mute is None:text('?',106,0)
  vol=status.get('volume')
  if vol is None:text('No audio' if app!='Offline' else 'Helper offline',0,21)
  else:
   text(str(vol)+'%',0,22);oled.rect(30,22,98,8,1);oled.fill_rect(32,24,int(94*vol/100),4,1)
 else:grid(engine.labels())
 oled.show()
while True:
 now=time.monotonic()
 # Read all key transitions before encoder button so same-scan Back wins.
 for i,p in enumerate(pins):
  v=not p.value
  if v!=raw[i]:raw[i]=v;changed[i]=now
  if v!=stable[i] and now-changed[i]>=.02:
   stable[i]=v;title_until=0
   k=i+1 if i<6 else 0
   if k==0 and v:engine.encoder_pressed(now)
   else:engine.key(k,v,now)
 newpos=enc.position
 if newpos!=pos:
  engine.rotate((newpos-pos)*cfg.get('encoder_direction',1));pos=newpos;title_until=0
 engine.tick(now)
 tag=(engine.page,engine.root,engine.course)
 if tag!=last_page:
  if engine.page in ('root','course','capcut','gaming'):
   title=engine.roots()[engine.root] if engine.page=='root' else engine.title
   title_until=now+.7
  last_page=tag
 if now-last_host>4:status={}
 if serial.connected:
  if now-last_ping>1:
   ping={'type':'hello','device':'hackpad','version':1,'os':engine.os,'generation':engine.generation,'page':engine.page}
   if len(queue)<24:queue.append((json.dumps(ping)+'\n').encode())
   last_ping=now
  if not tx and queue:tx=queue.pop(0)
  if tx:
   try:
    n=serial.write(tx) or 0;tx=tx[n:]
   except OSError:tx=b''
  data=serial.read(256)
  if data:rx.extend(data)
  if len(rx)>4096:rx=bytearray()
  while b'\n' in rx:
   line,_,rx=rx.partition(b'\n');rx=bytearray(rx)
   try:
    msg=json.loads(line)
    if not isinstance(msg,dict) or msg.get('version')!=1:continue
    last_host=now
    if msg.get('type')=='status':status=msg
    elif msg.get('type')=='result' and msg.get('generation')==engine.generation:
     notice=str(msg.get('text',''))[:63]
     if notice:notice_until=now+3
   except (ValueError,TypeError):pass
 else:queue=[];tx=b'';rx=bytearray()
 if now-last_draw>.1:draw(now);last_draw=now
 time.sleep(.002)

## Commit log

2026-09-17 Add AI-assisted Hackpad design prototype and documented validation
    [BOM.csv, Base.step, Base.stl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]
2026-09-18 Recover browser failures through manual fallback and allow reopening
    [browser_workflows.py, test_browser_fallback.py]
